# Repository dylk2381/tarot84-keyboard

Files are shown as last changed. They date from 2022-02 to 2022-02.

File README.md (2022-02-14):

# tarot84-keyboard
An 84-key 65%+numpad keyboard. Name is just something I decided like 95% of the way through :P.

## A note
I am actually unsure if this works properly at the moment. I am planning on ordering some prototype PCBs whenever some of the components come back in stock. As of now, this is just a fun side project that I decided to throw up on github. This is my first time designing *any* PCB.

## Specifications
 - 84 keys
 - Alpha, Numbers, Numpad, Nav keys
 - Supports MX-Style switches (3pin or 5pin)
 - Supports QMK (Not sure about any alternatives, should be anything compatible with the ATMEGA32U4-A)
 - Soldered

## Component List
NOTE: All of the components on this list are just what I have found, they should work with anything that is equivalent.
 - 1x ATMEGA32U4-A TQFB Package Microcontroller
 - 84x YFW 1N4148WS Diodes
 - 2x CL21C220JBANNNC Capacitors
 - 2x 0805W8F220JT5E Resistors
 - 3x C0805C104K3REC7800 Capacitors
 - 1x 0805B105K250NT Capacitor
 - 1x 0805X106K250NT Capacitor
 - 2x 0805W8F1002T5E Resistors
 - 1x X322516MLB4SI Crystal
 - 1x RS-187R05A2-DS MT RT Switch
 - 1x SM04B-SRSS-TB(LF)(SN) 4 Pin Connector

## Required Libraries
https://github.com/ai03-2725/MX_Alps_Hybrid
https://github.com/egladman/keebs.pretty
https://github.com/tmk/keyboard_parts.pretty
https://github.com/ai03-2725/Unified-Daughterboard
https://github.com/ai03-2725/random-keyboard-parts.pretty
https://github.com/tmk/kicad_lib_tmk

## Assembly
I believe everything on this board *should* be able to be hand soldered, albeit designed with just ordering assembly online in mind. If you are assembling, I would strongly recommend not relying entirely on the silkscreening.

## Additional Info
Screenshots are in the folder labelled "Screenshots."

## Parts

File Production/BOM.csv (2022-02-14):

Comment | Designator | Footprint | LCSC
.1uF | C1,C4,C6 | Capacitor_SMD:C_0805_2012Metric_Pad1.18x1.45mm_HandSolder
22pF | C2,C3 | Capacitor_SMD:C_0805_2012Metric_Pad1.18x1.45mm_HandSolder
1uF | C5 | Capacitor_SMD:C_0805_2012Metric_Pad1.18x1.45mm_HandSolder
10uF | C7 | Capacitor_SMD:C_0805_2012Metric_Pad1.18x1.45mm_HandSolder
D_Small | D1,D2,D3,D4,D5,D6,D7,D8,D9,D10,D11,D12,D13,D14,D15,D16,D17,D18,D19,D20,D21,D22,D23,D24,D25,D26,D27,D28,D29,D30,D31,D32,D33,D34,D35,D36,D37,D38,D39,D40,D41,D42,D43,D44,D45,D46,D47,D48,D49,D50,D51,D52,D53,D54,D55,D56,D57,D58,D59,D60,D61,D62,D63,D64,D65,D66,D67,D68,D69,D70,D71,D72,D73,D74,D75,D76,D77,D78,D79,D80,D81,D82,D83,D84 | Diode_SMD:D_SOD-123
SM04B-SRSS-TB(LF)(SN) | J1 | random-keyboard-parts:JST-SR-4
KEYSW | K1,K2,K3,K4,K5,K6,K7,K8,K9,K10,K11,K12,K13,K14,K15,K16,K17,K18,K19,K20,K21,K22,K23,K24,K25,K26,K27,K28,K29,K30,K31,K32,K33,K34,K35,K36,K37,K38,K39,K40,K41,K42,K43,K44,K45,K46,K47,K48,K49,K50,K51,K52,K53,K54,K55,K56,K57,K58,K59,K60,K61,K62,K63,K64,K65,K66,K67,K68,K69,K70,K71,K72,K73,K74,K75,K76,K77,K78,K79,K80,K81,K82,K83,K84 | MX_Only:MXOnly-1U-NoLED
22 | R1,R2 | Resistor_SMD:R_0805_2012Metric
10k | R3,R4 | Resistor_SMD:R_0805_2012Metric
SW_PUSH | SW1 | random-keyboard-parts:SKQG-1155865
ATmega32U4-A | U1 | Package_QFP:TQFP-44_10x10mm_P0.8mm
16MHz | Y1 | Crystal:Crystal_SMD_3225-4Pin_3.2x2.5mm

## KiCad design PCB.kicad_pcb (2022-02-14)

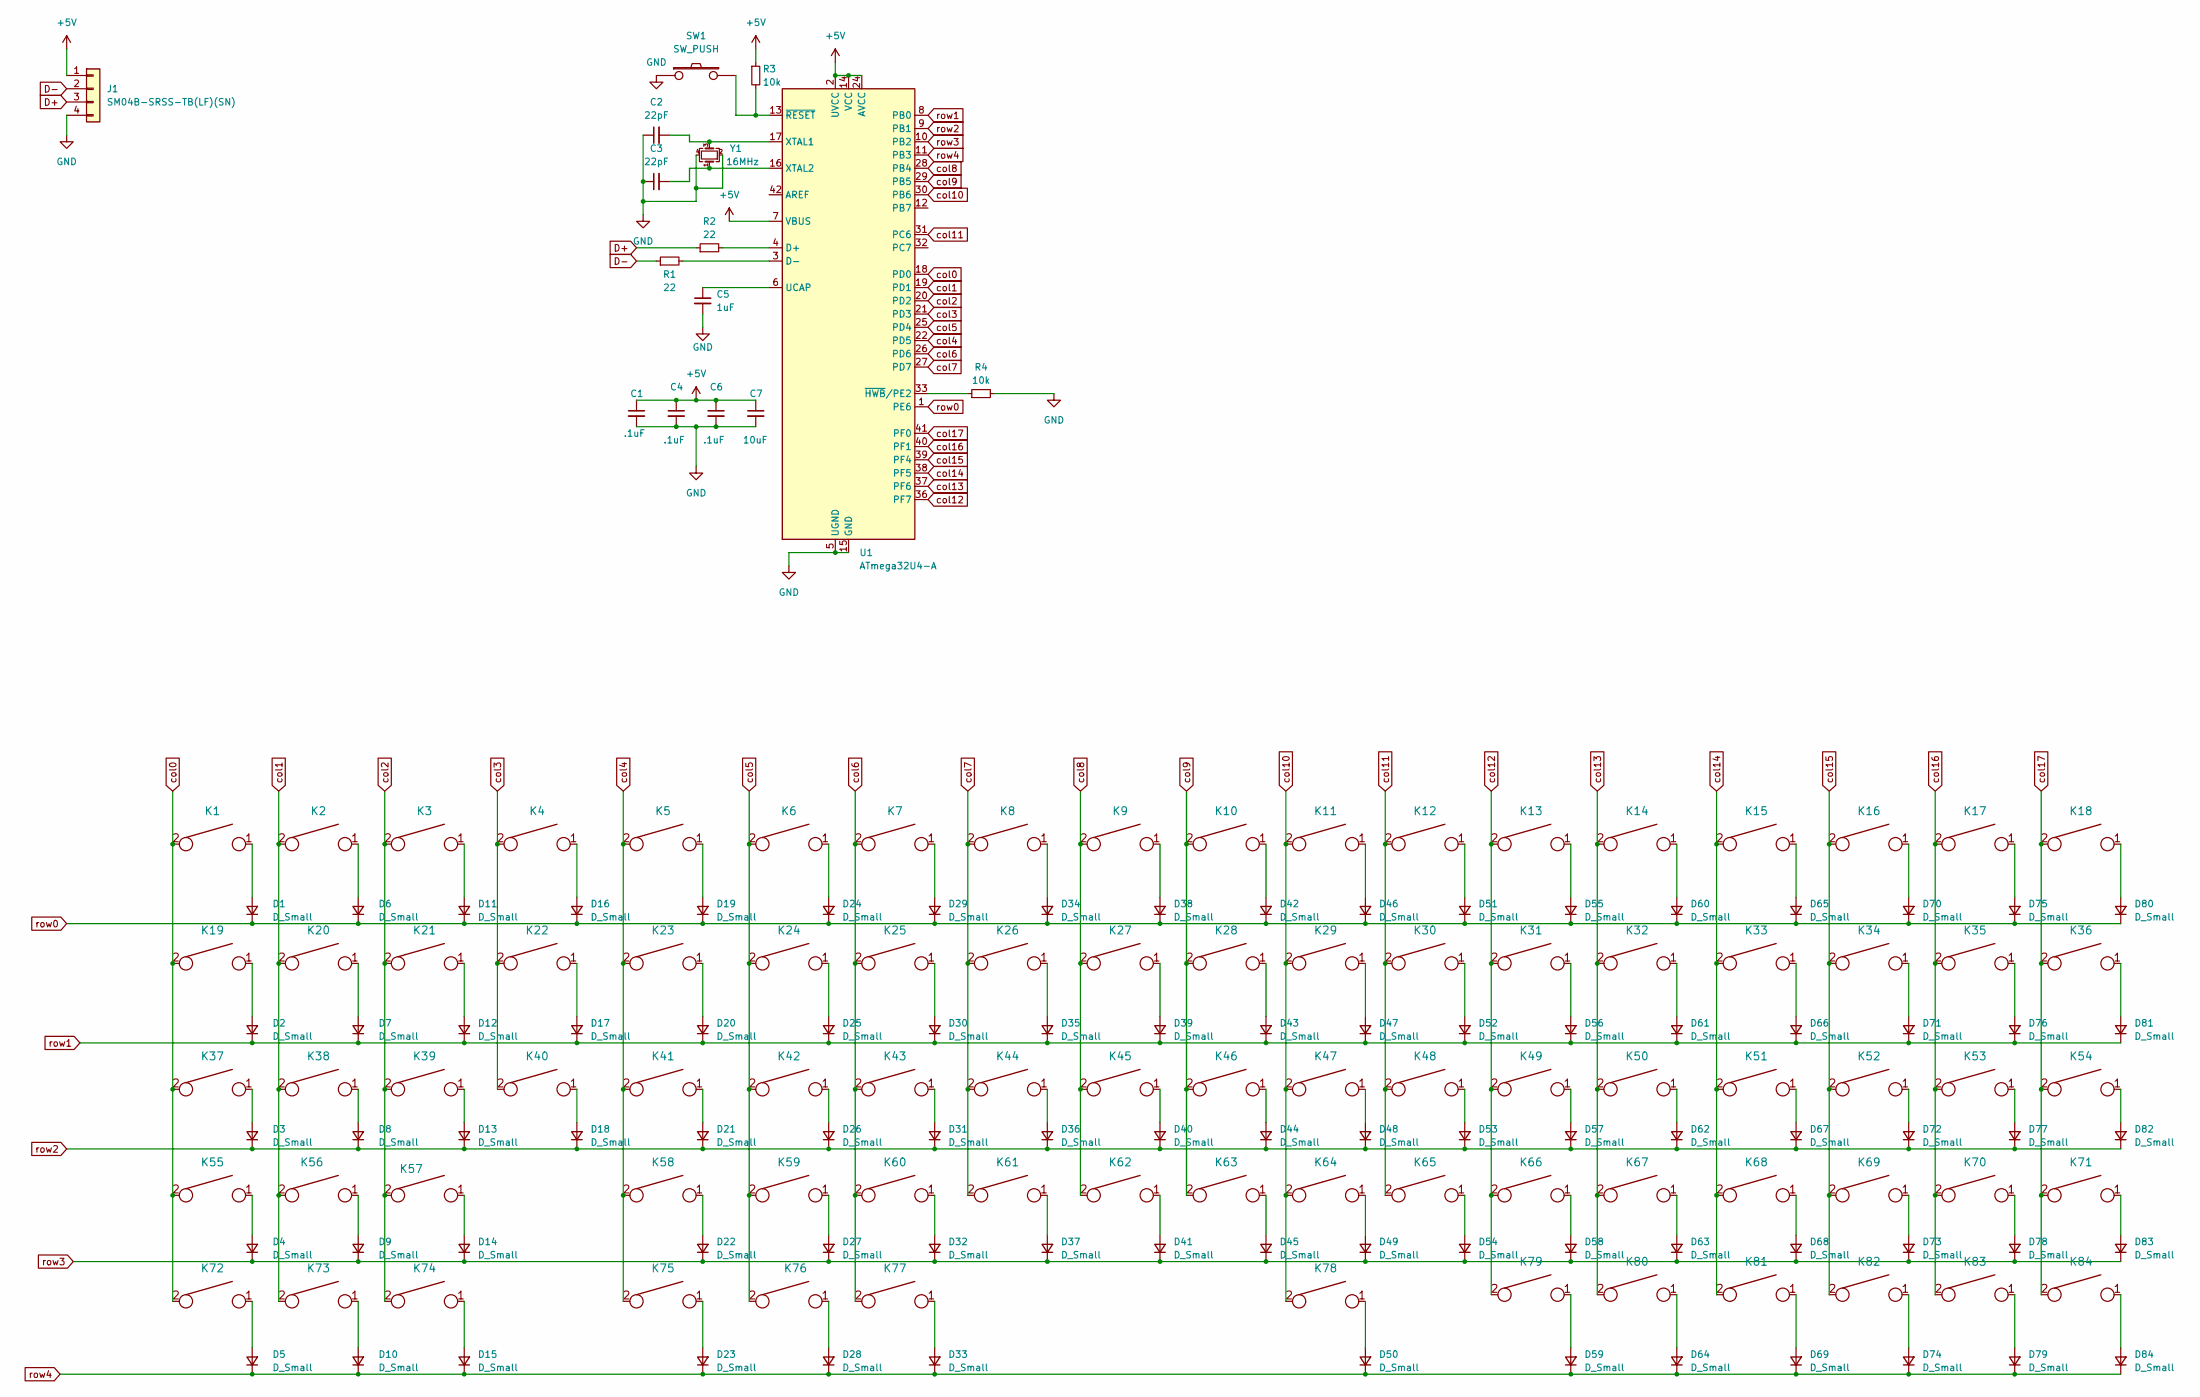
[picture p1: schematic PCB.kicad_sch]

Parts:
C1, C4, C6: .1uF; C_0805_2012Metric_Pad1.18x1.45mm_HandSolder
C2, C3: 22pF; C_0805_2012Metric_Pad1.18x1.45mm_HandSolder
C5: 1uF; C_0805_2012Metric_Pad1.18x1.45mm_HandSolder
C7: 10uF; C_0805_2012Metric_Pad1.18x1.45mm_HandSolder
D1, D2, D3, D4, D5, D6, D7, D8, D9, D10, D11, D12, D13, D14, D15, D16, D17, D18, D19, D20, D21, D22, D23, D24, D25, D26, D27, D28, D29, D30, D31, D32, D33, D34, D35, D36, D37, D38, D39, D40, D41, D42, D43, D44, D45, D46, D47, D48, D49, D50, D51, D52, D53, D54, D55, D56, D57, D58, D59, D60, D61, D62, D63, D64, D65, D66, D67, D68, D69, D70, D71, D72, D73, D74, D75, D76, D77, D78, D79, D80, D81, D82, D83, D84: D_Small; D_SOD-123
J1: SM04B-SRSS-TB(LF)(SN); JST-SR-4
K1, K2, K3, K4, K5, K6, K7, K8, K9, K10, K11, K12, K13, K14, K15, K16, K17, K18, K19, K20, K21, K22, K23, K24, K25, K26, K27, K28, K29, K30, K31, K32, K33, K34, K35, K36, K37, K38, K39, K40, K41, K42, K43, K44, K45, K46, K47, K48, K49, K50, K51, K52, K53, K54, K55, K56, K57, K58, K59, K60, K61, K62, K63, K64, K65, K66, K67, K68, K69, K70, K71, K72, K73, K74, K75, K76, K77, K78, K79, K80, K81, K82, K83, K84: KEYSW; MXOnly-1U-NoLED
R1, R2: 22; R_0805_2012Metric
R3, R4: 10k; R_0805_2012Metric
SW1: SW_PUSH; SKQG-1155865
U1: ATmega32U4-A; TQFP-44_10x10mm_P0.8mm
Y1: 16MHz; Crystal_SMD_3225-4Pin_3.2x2.5mm

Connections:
+5V: C1.1, C4.1, C6.1, C7.1, J1.1, R3.1, U1.2 (UVCC), U1.7 (VBUS), U1.14 (VCC), U1.24 (AVCC), U1.34 (VCC), U1.44 (AVCC)
D+: J1.3, R2.1
D-: J1.2, R1.1
GND: C1.2, C2.1, C3.1, C4.2, C5.2, C6.2, C7.2, J1.4, R4.2, SW1.1, U1.5 (UGND), U1.15 (GND), U1.23 (GND), U1.35 (GND), U1.43 (GND), Y1.2, Y1.4
unnamed: C2.2, U1.17 (XTAL1), Y1.3
unnamed: C3.2, U1.16 (XTAL2), Y1.1
unnamed: C5.1, U1.6 (UCAP)
unnamed: D1.2 (A), K1.1
unnamed: D2.2 (A), K19.1
unnamed: D3.2 (A), K37.1
unnamed: D4.2 (A), K55.1
unnamed: D5.2 (A), K72.1
unnamed: D6.2 (A), K2.1
unnamed: D7.2 (A), K20.1
unnamed: D8.2 (A), K38.1
unnamed: D9.2 (A), K56.1
unnamed: D10.2 (A), K73.1
unnamed: D11.2 (A), K3.1
unnamed: D12.2 (A), K21.1
unnamed: D13.2 (A), K39.1
unnamed: D14.2 (A), K57.1
unnamed: D15.2 (A), K74.1
unnamed: D16.2 (A), K4.1
unnamed: D17.2 (A), K22.1
unnamed: D18.2 (A), K40.1
unnamed: D19.2 (A), K5.1
unnamed: D20.2 (A), K23.1
unnamed: D21.2 (A), K41.1
unnamed: D22.2 (A), K58.1
unnamed: D23.2 (A), K75.1
unnamed: D24.2 (A), K6.1
unnamed: D25.2 (A), K24.1
unnamed: D26.2 (A), K42.1
unnamed: D27.2 (A), K59.1
unnamed: D28.2 (A), K76.1
unnamed: D29.2 (A), K7.1
unnamed: D30.2 (A), K25.1
unnamed: D31.2 (A), K43.1
unnamed: D32.2 (A), K60.1
unnamed: D33.2 (A), K77.1
unnamed: D34.2 (A), K8.1
unnamed: D35.2 (A), K26.1
unnamed: D36.2 (A), K44.1
unnamed: D37.2 (A), K61.1
unnamed: D38.2 (A), K9.1
unnamed: D39.2 (A), K27.1
unnamed: D40.2 (A), K45.1
unnamed: D41.2 (A), K62.1
unnamed: D42.2 (A), K10.1
unnamed: D43.2 (A), K28.1
unnamed: D44.2 (A), K46.1
unnamed: D45.2 (A), K63.1
unnamed: D46.2 (A), K11.1
unnamed: D47.2 (A), K29.1
unnamed: D48.2 (A), K47.1
unnamed: D49.2 (A), K64.1
unnamed: D50.2 (A), K78.1
unnamed: D51.2 (A), K12.1
unnamed: D52.2 (A), K30.1
unnamed: D53.2 (A), K48.1
unnamed: D54.2 (A), K65.1
unnamed: D55.2 (A), K13.1
unnamed: D56.2 (A), K31.1
unnamed: D57.2 (A), K49.1
unnamed: D58.2 (A), K66.1
unnamed: D59.2 (A), K79.1
unnamed: D60.2 (A), K14.1
unnamed: D61.2 (A), K32.1
unnamed: D62.2 (A), K50.1
unnamed: D63.2 (A), K67.1
unnamed: D64.2 (A), K80.1
unnamed: D65.2 (A), K15.1
unnamed: D66.2 (A), K33.1
unnamed: D67.2 (A), K51.1
unnamed: D68.2 (A), K68.1
unnamed: D69.2 (A), K81.1
unnamed: D70.2 (A), K16.1
unnamed: D71.2 (A), K34.1
unnamed: D72.2 (A), K52.1
unnamed: D73.2 (A), K69.1
unnamed: D74.2 (A), K82.1
unnamed: D75.2 (A), K17.1
unnamed: D76.2 (A), K35.1
unnamed: D77.2 (A), K53.1
unnamed: D78.2 (A), K70.1
unnamed: D79.2 (A), K83.1
unnamed: D80.2 (A), K18.1
unnamed: D81.2 (A), K36.1
unnamed: D82.2 (A), K54.1
unnamed: D83.2 (A), K71.1
unnamed: D84.2 (A), K84.1
unnamed: R1.2, U1.3 (D-)
unnamed: R2.2, U1.4 (D+)
unnamed: R3.2, SW1.2, U1.13 (~RESET)
unnamed: R4.1, U1.33 (~HWB/PE2)
col0: K1.2, K19.2, K37.2, K55.2, K72.2, U1.18 (PD0)
col1: K2.2, K20.2, K38.2, K56.2, K73.2, U1.19 (PD1)
col2: K3.2, K21.2, K39.2, K57.2, K74.2, U1.20 (PD2)
col3: K4.2, K22.2, K40.2, U1.21 (PD3)
col4: K5.2, K23.2, K41.2, K58.2, K75.2, U1.22 (PD5)
col5: K6.2, K24.2, K42.2, K59.2, K76.2, U1.25 (PD4)
col6: K7.2, K25.2, K43.2, K60.2, K77.2, U1.26 (PD6)
col7: K8.2, K26.2, K44.2, K61.2, U1.27 (PD7)
col8: K9.2, K27.2, K45.2, K62.2, U1.28 (PB4)
col9: K10.2, K28.2, K46.2, K63.2, U1.29 (PB5)
col10: K11.2, K29.2, K47.2, K64.2, K78.2, U1.30 (PB6)
col11: K12.2, K30.2, K48.2, K65.2, U1.31 (PC6)
col12: K13.2, K31.2, K49.2, K66.2, K79.2, U1.36 (PF7)
col13: K14.2, K32.2, K50.2, K67.2, K80.2, U1.37 (PF6)
col14: K15.2, K33.2, K51.2, K68.2, K81.2, U1.38 (PF5)
col15: K16.2, K34.2, K52.2, K69.2, K82.2, U1.39 (PF4)
col16: K17.2, K35.2, K53.2, K70.2, K83.2, U1.40 (PF1)
col17: K18.2, K36.2, K54.2, K71.2, K84.2, U1.41 (PF0)
row0: D1.1 (K), D6.1 (K), D11.1 (K), D16.1 (K), D19.1 (K), D24.1 (K), D29.1 (K), D34.1 (K), D38.1 (K), D42.1 (K), D46.1 (K), D51.1 (K), D55.1 (K), D60.1 (K), D65.1 (K), D70.1 (K), D75.1 (K), D80.1 (K), U1.1 (PE6)
row1: D2.1 (K), D7.1 (K), D12.1 (K), D17.1 (K), D20.1 (K), D25.1 (K), D30.1 (K), D35.1 (K), D39.1 (K), D43.1 (K), D47.1 (K), D52.1 (K), D56.1 (K), D61.1 (K), D66.1 (K), D71.1 (K), D76.1 (K), D81.1 (K), U1.8 (PB0)
row2: D3.1 (K), D8.1 (K), D13.1 (K), D18.1 (K), D21.1 (K), D26.1 (K), D31.1 (K), D36.1 (K), D40.1 (K), D44.1 (K), D48.1 (K), D53.1 (K), D57.1 (K), D62.1 (K), D67.1 (K), D72.1 (K), D77.1 (K), D82.1 (K), U1.9 (PB1)
row3: D4.1 (K), D9.1 (K), D14.1 (K), D22.1 (K), D27.1 (K), D32.1 (K), D37.1 (K), D41.1 (K), D45.1 (K), D49.1 (K), D54.1 (K), D58.1 (K), D63.1 (K), D68.1 (K), D73.1 (K), D78.1 (K), D83.1 (K), U1.10 (PB2)
row4: D5.1 (K), D10.1 (K), D15.1 (K), D23.1 (K), D28.1 (K), D33.1 (K), D50.1 (K), D59.1 (K), D64.1 (K), D69.1 (K), D74.1 (K), D79.1 (K), D84.1 (K), U1.11 (PB3)

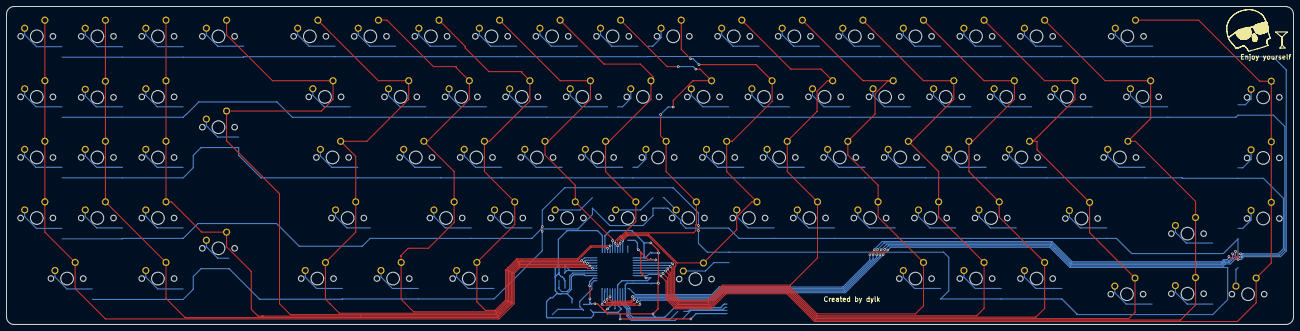
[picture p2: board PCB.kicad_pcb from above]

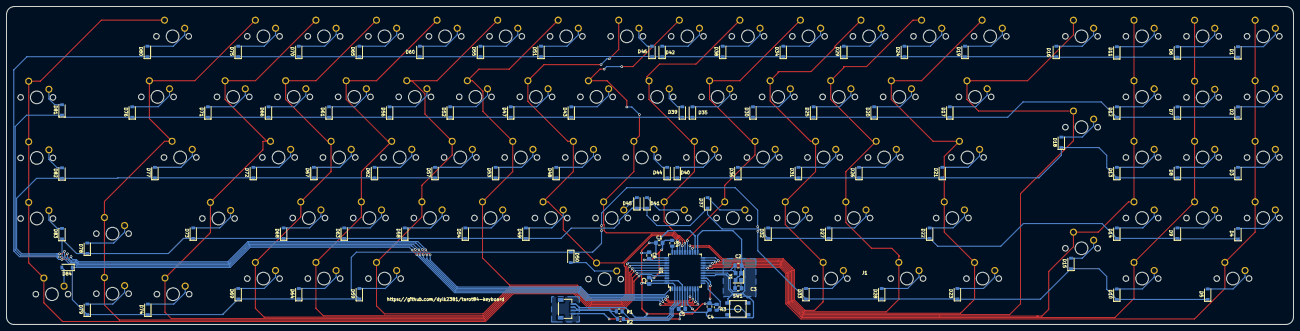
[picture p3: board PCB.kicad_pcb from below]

Board: 2 copper layers, 404.8 x 100.0 mm, 183 parts (99 on the bottom side), 118 nets.
